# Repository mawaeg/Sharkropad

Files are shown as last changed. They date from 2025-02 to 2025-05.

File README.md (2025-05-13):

# Sharkropad

**Sharkropad** is an open-source hotswappable macropad supporting QMK/VIA.

This repository includes a custom pcb design, a 3d printed case and QMK/VIA firmware.

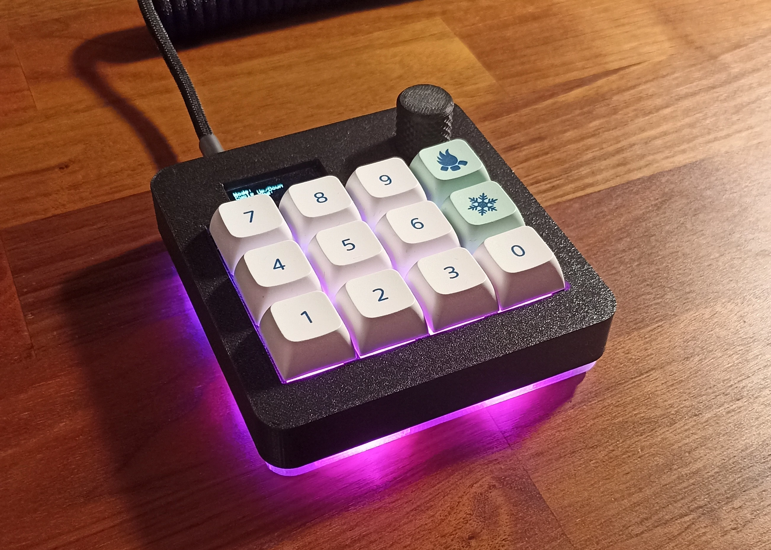
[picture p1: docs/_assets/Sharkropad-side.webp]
Sharkropad Logo


## Features
- **USB-C with ESD Protection**
- **Rotary Encoder**
- **OLED Display**
- **Customizable RGB Lighting**
- **Customizable keymap using VIA**
- **Hot-Swappable Switches**
- **Powered by a STM32L432 MCU**

## Getting Started

### Pcb

The Sharkropad is based on a custom pcb. You can find the manufacturing files in the latest release.

I got my pcb manufactured and assembled from [JLCPCB](https://jlcpcb.com/).

In case you want to assemble the pcb yourself you can find all the needed parts in the bom in the latest release.

### Other needed parts

| Part | Quantity  | Link (recommendation) | Note |
|---|---|---|---|
| filament of your choice | 50g | [3djake.de](https://www.3djake.de/polymaker/polyterra-pla-charcoal-black) | For the top parts (I used a matte black PLA filament)
| transparent filament | 30g | [redline-filament.com](https://redline-filament.com/collections/pla-filament/products/premium-pla-transparent?variant=50149105041672) | Transparent bottom parts for the underglow
| M2.5 Heat Inserts | 4 | [cnckitchen.store](https://cnckitchen.store/products/gewindeeinsatz-threaded-insert-m2-5-standard-100-stk-pcs) |
| M2.5 x 12 Screws | 4 | [cnckitchen.store](https://cnckitchen.store/products/m2-5-screw-stainless-steel-aisi-304-low-head?variant=47945362833743) |
| Protective buffer | 4 | [amazon.de](https://www.amazon.de/dp/B01N0X4Y38?ref=ppx_yo2ov_dt_b_fed_asin_title&th=1) |
| Keycaps | 12 | [aliexpress.com](https://de.aliexpress.com/item/1005006660909685.html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)
| Stranded wire | 10cm | tbd | Currently there is a problem with the pcb when using the underglow leds where a cable needs to be soldered
| Rotary Encoder | 1 | [42keebs.eu](https://42keebs.eu/shop/parts/ec11-rotary-encoder/?attribute_type=Bourns%20(larger%20body)) | This particular one works with the case and the knob
| OLED display | 1 | [42keebs.eu](https://42keebs.eu/shop/parts/oled-display-0-91-128x32/?attribute_pcb-colour=Black)
| OLED socket (low profile) | 1 | [42keebs.eu](https://42keebs.eu/shop/parts/low-profile-oled-sockets/) 
| Hotswap sockets | 12 | [42keebs.eu](https://42keebs.eu/shop/parts/kailh-mx-hot-swap-sockets/) | (2 x 10 sockets) !Cherry MX-style!
| Switches | 12 | [candykeys.com](https://candykeys.com/product/hmx-silent-sakura) | Any MX compatible switch is fine

### 3d printed case

The case consists of 4 3d printed parts:
- Bottom part of the case
- Top part of the case
- Plate for the switches
- Rotary encoder knob

The stl files for the 3d printed parts can be found under [cad/stl/](cad/stl/).

The parts are created with [OpenSCAD](https://openscad.org/) and the source code is stored at [cad/](cad/).

#### Print settings

For the bottom part of the case I used transparent PLA to make the underglow leds shine through.

For the top part of the case, the plate and the rotary encoder knob I used matte black PLA.

I printed the case and the plate with default print settings with a layer height of .2mm.

> **_NOTE:_** For the top and bottom case you will need some supports for the cutouts for the encoder and the screw heads. Default support settings should work just fine. (I like to use organic supports.)

The rotary encoder knob should be printed with a layer height of .2mm and at least 3 solid bottom layers.

### Building the Sharkropad

1. Get a PCB and prepare it by soldering the components onto it (if not already done through SMT assembly)
2. Assemble the rotary encoder, the oled socket and the hotswap sockets (if not already done)
3. Fix the issue with the pcb as shown in [this chapter](#fixing-the-pcb)

    <div style="display: flex;">
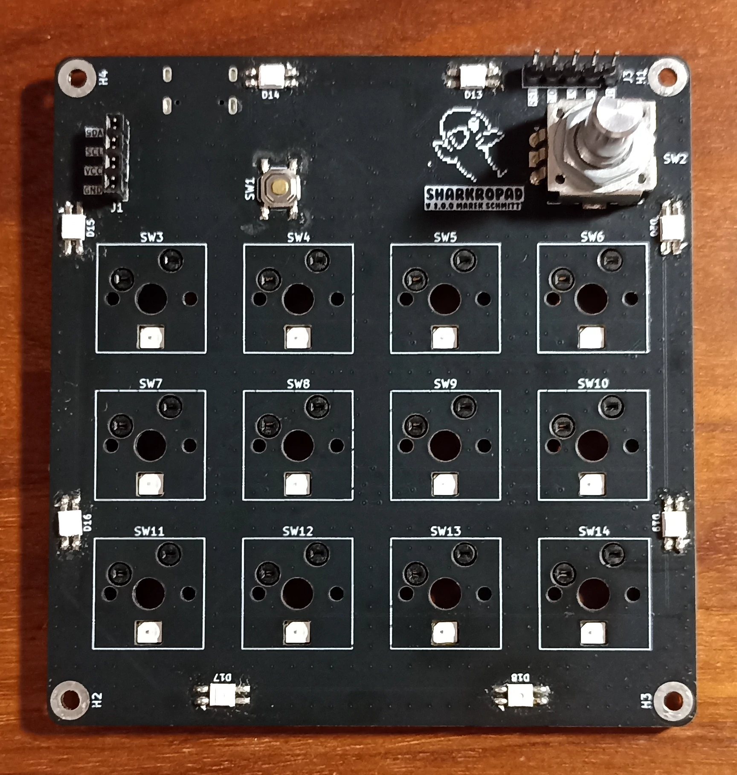
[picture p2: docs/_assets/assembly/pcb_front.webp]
        
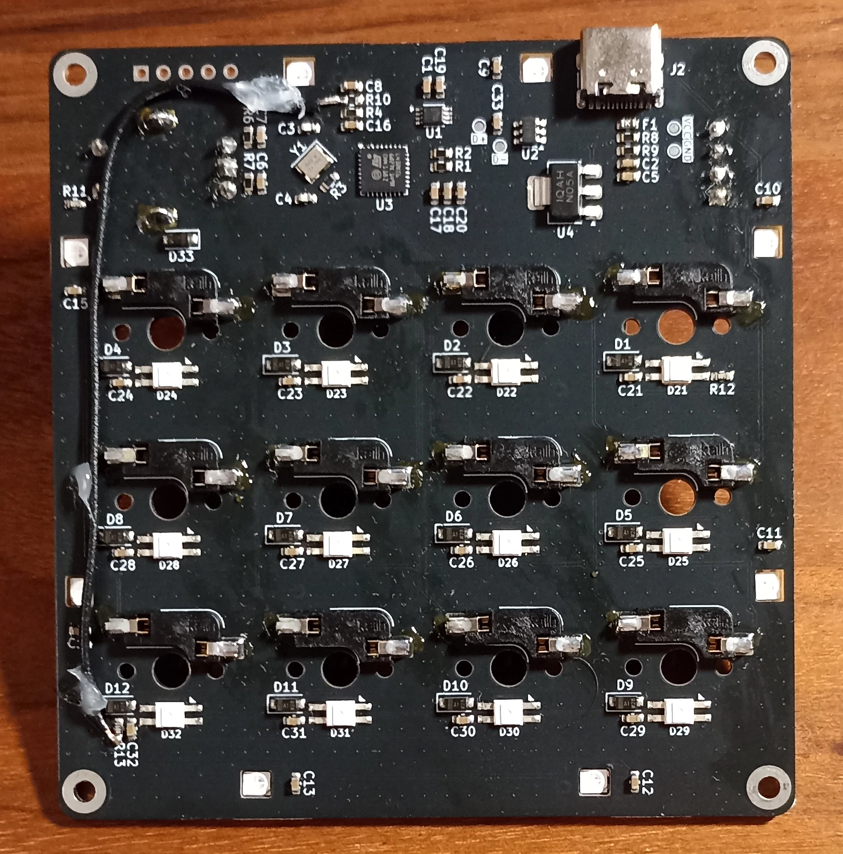
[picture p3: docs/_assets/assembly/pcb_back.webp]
        
    </div>

4. Place a foam (as shown) to support the OLED and mount the oled:

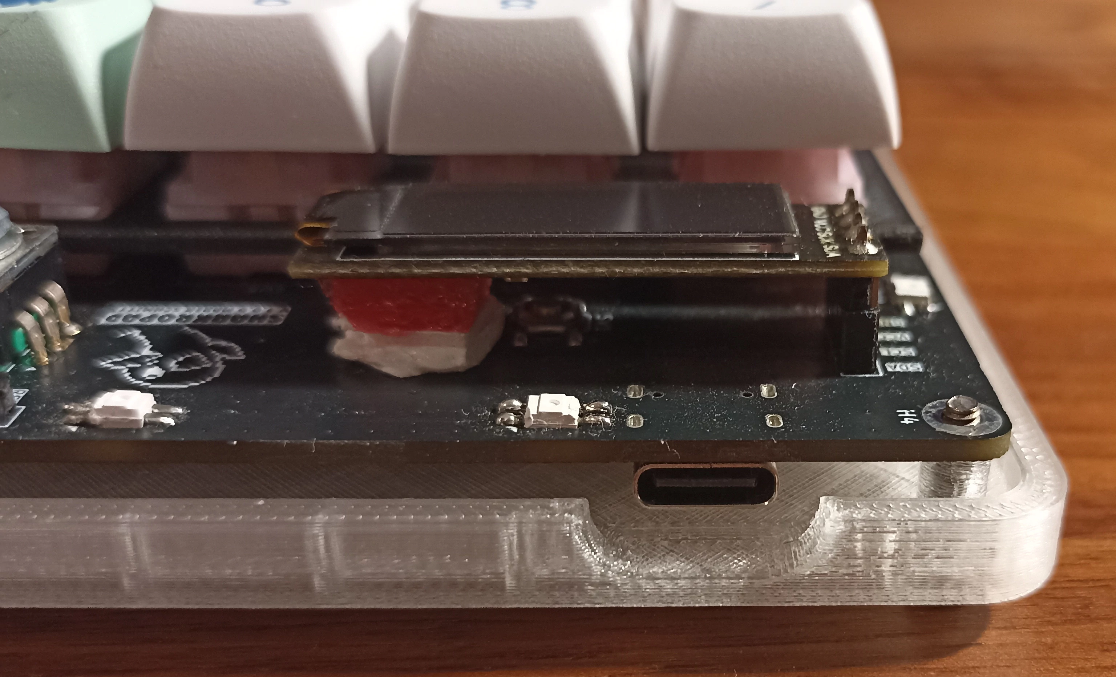
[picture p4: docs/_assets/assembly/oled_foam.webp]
     

5. Assemble the switches (put the plate between pcb and switches) and the keycaps
6. Insert the heat inserts into the holes provided in the top part:

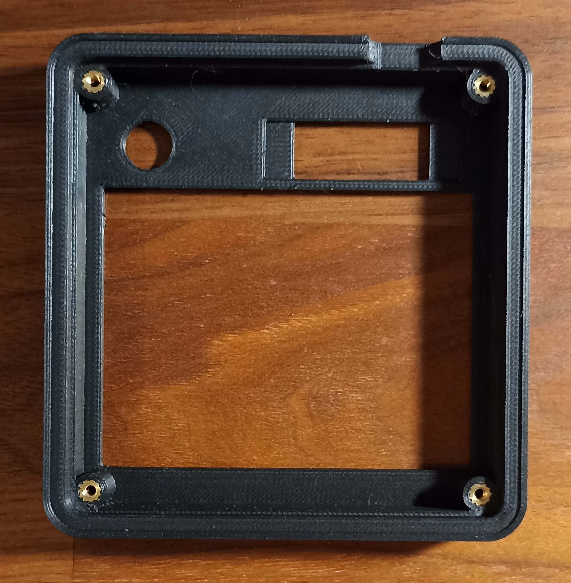
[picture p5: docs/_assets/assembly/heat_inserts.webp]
Heat inserts
    

7. Put the protective buffers on the bottom case to prevent the macropad from sliding around:

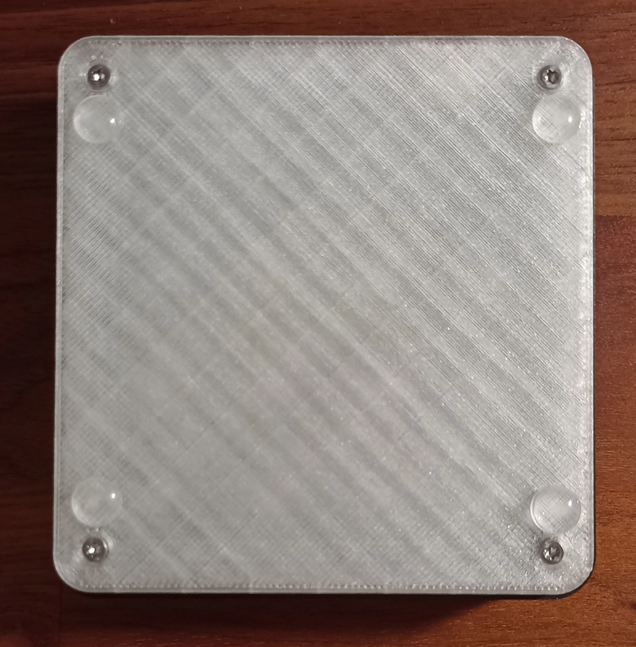
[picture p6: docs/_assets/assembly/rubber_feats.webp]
    

8. Screw the case together with the pcb in between and put the knob on the rotary encoder

### Flashing the firmware

> **_NOTE:_** Once the firmware is flashed once you can enter bootloader mode by disconnecting the macropad, pressing and holding the encoder knob while plugging it back in. Then the macropad is in bootloader mode and you can connect to it  and program it using the CubeProgrammer or flash using QMK.

1. Get the provided firmware in the latest release
    - If you want to be able to use VIA to modify the keymap you should use `sharkropad_via.bin`
    - If you only need QMK functionality you can also use ` sharkropad_default.bin`
    
2. Flash the firmware using the [STM32 CubeProgrammer](https://www.st.com/en/development-tools/stm32cubeprog.html) as shown below:

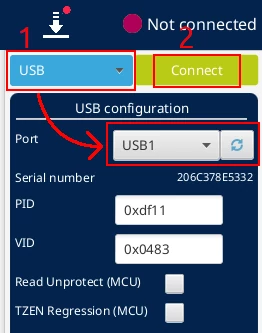
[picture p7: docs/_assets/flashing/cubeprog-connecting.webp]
Cube Programmer connecting

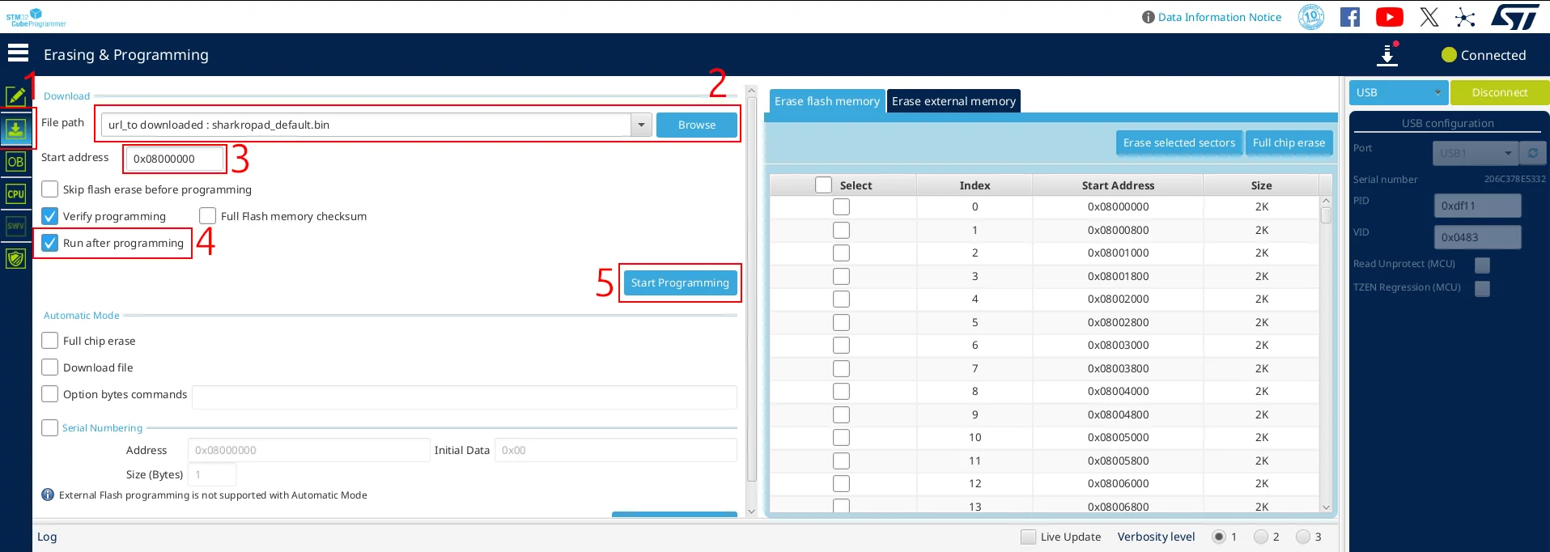
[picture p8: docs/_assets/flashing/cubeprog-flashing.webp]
Cube Programmer flashing


#### Flash using QMK

As the firmware is not currently in the qmk github repository flashing with QMK is more complicated.
- You need to setup your QMK Environment
- Copy the firmware into the QMK folder:
    - Copy the contents of the firmware folder to a folder named `sharkropad` under `qmk_firmware/keyboards`
    - Target structure: `qmk_firmware/keyboards/sharkropad`:

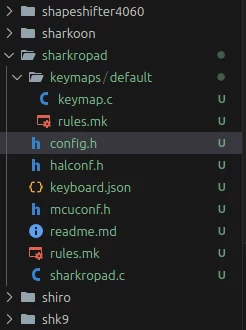
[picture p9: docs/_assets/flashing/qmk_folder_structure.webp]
QMK folder structure
      
- You can then compile and flash using qmk:
    ```shell
    qmk compile -kb sharkropad -km default
    qmk flash -kb sharkropad -km default
    ```

    or for via compatible firmware:
    ```shell
    qmk compile -kb sharkropad -km via
    qmk flash -kb sharkropad -km via
    ```

### Fixing the pcb

In the current design of the pcb, the rgb underglow and the rgb matrix for the keys are connected to different Output pins of the STM32.
However that is not supported by QMK. Therefore a cable needs to be manually soldered to also make the rgb underglow working:
- Remove the resistor R10
- Solder a cable from the left contact of R10 to the bottom contact of R13

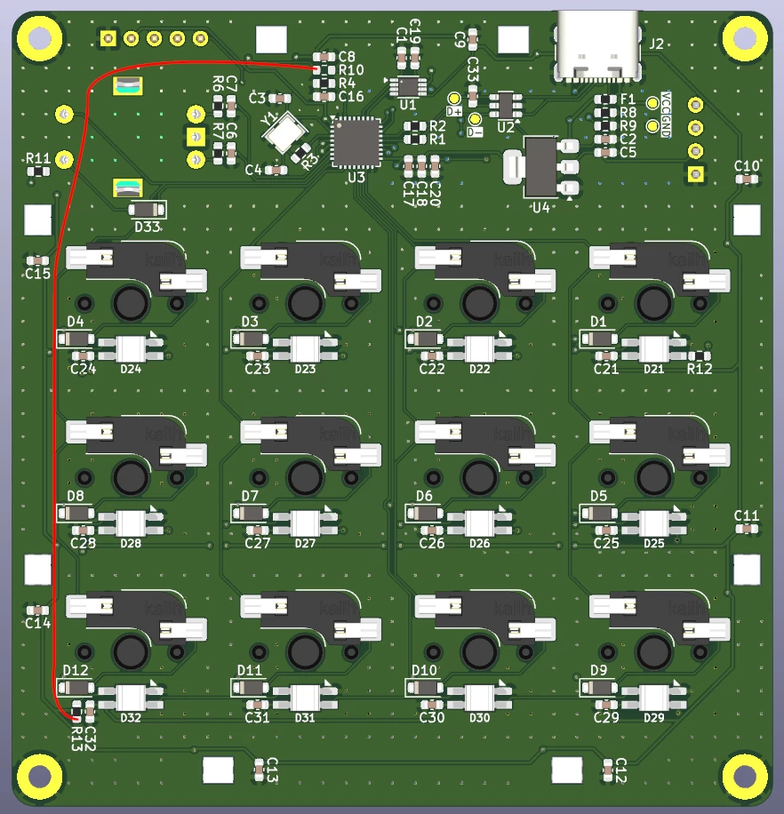
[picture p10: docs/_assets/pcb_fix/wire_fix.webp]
Pcb fix
    

## Customize the keymap using VIA

VIA is a tool that allows you to customize the keymap of your keyboard.

As the configuration for this macropad is not yet added to the via repository a manual step is needed to customize using VIA.

1. Open the VIA web app at [https://usevia.app/](https://usevia.app/)
2. Navigate to the settings and ensure the `Show Design tab` option is enabled

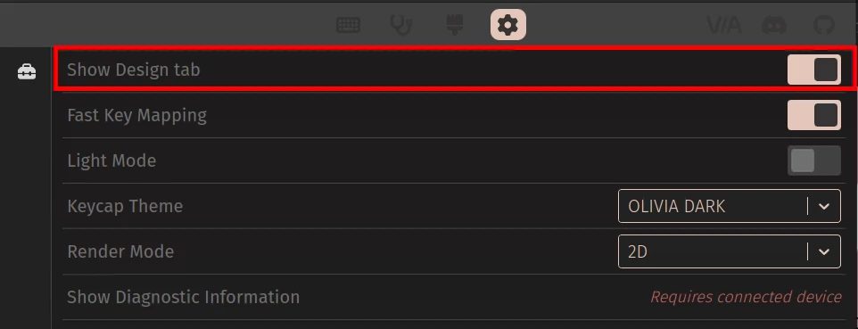
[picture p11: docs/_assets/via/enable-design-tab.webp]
Enable Design Tab
    

3. Open the design tab and press `Load` (Draft Definition)

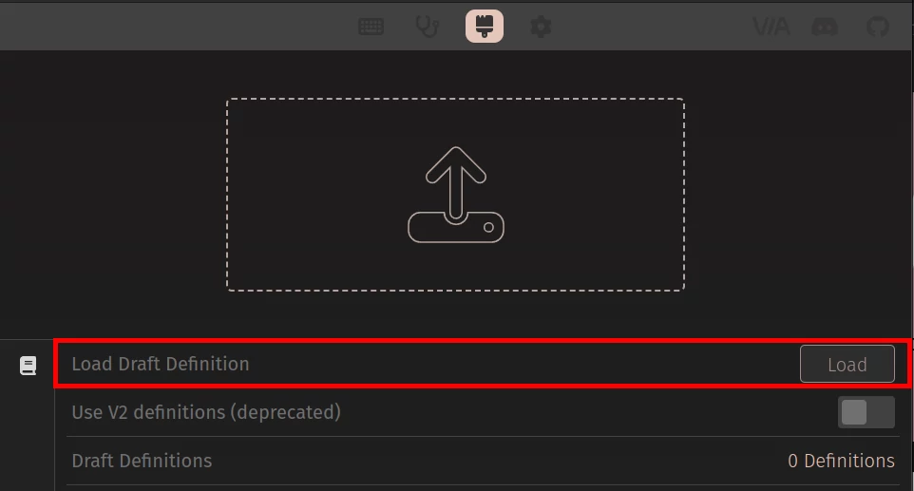
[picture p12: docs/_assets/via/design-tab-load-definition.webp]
Load definition
    

4. Select the `via.json` provided in this release. You should now see a model of the macropad:

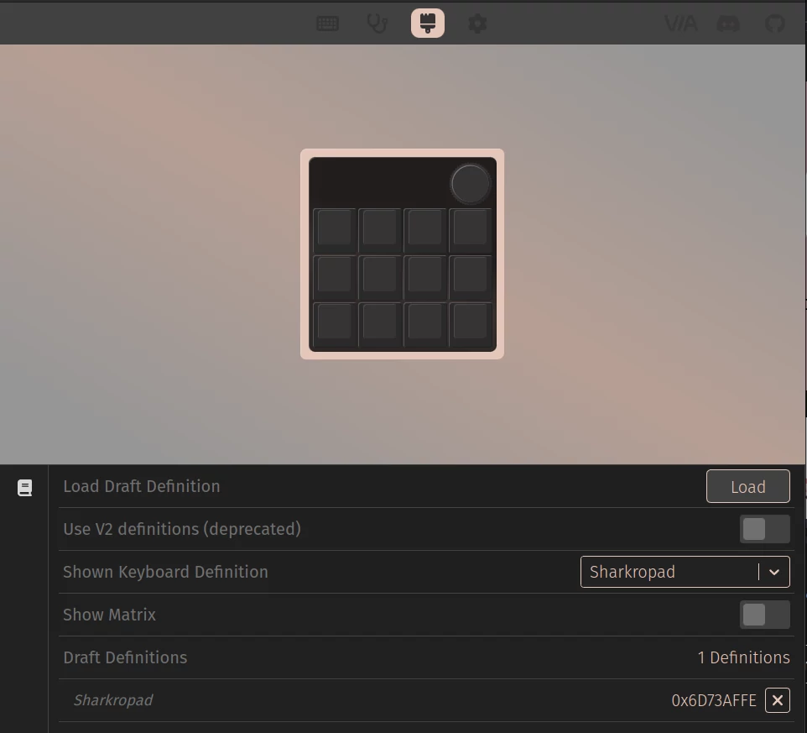
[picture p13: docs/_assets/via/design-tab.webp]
Design Tab Overview
    

5. You can now open the Customize window where you need to click `Authorize device +`

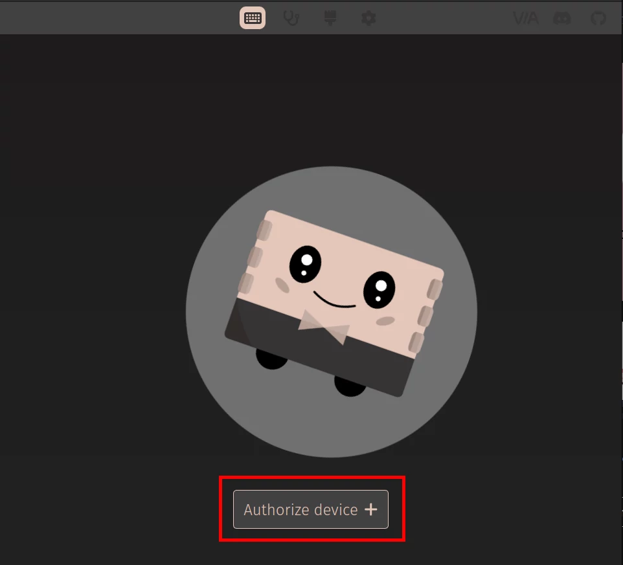
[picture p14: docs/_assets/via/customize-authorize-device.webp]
Authorize device
    

6. Select the device with Sharkropad in its name

You can now customize the individual keys and also customize the RGB Lighting:

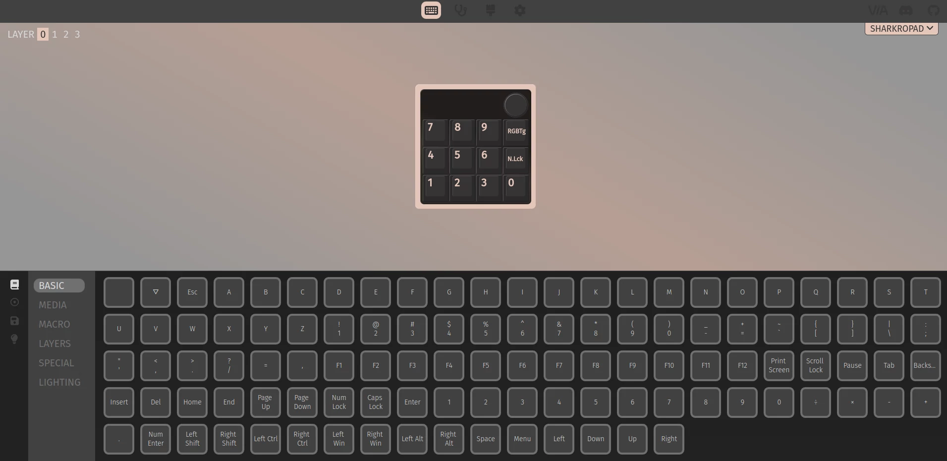
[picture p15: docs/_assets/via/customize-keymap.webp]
Customize keymap

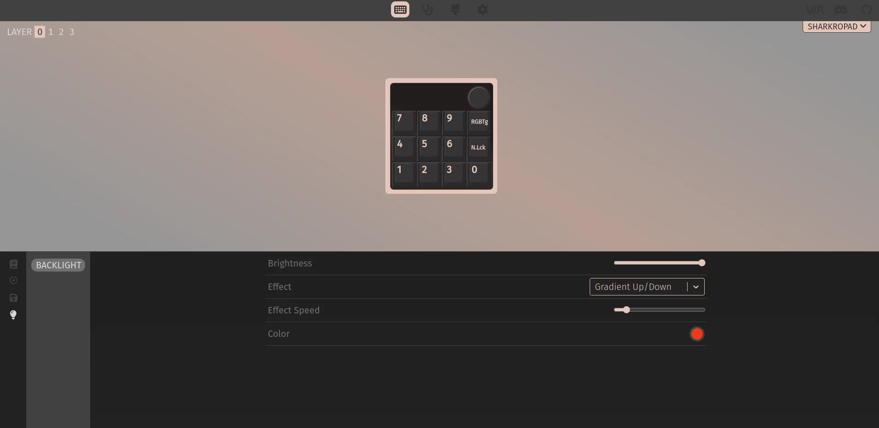
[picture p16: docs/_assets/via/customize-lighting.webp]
Customize lighting


## License

This project is licensed under the GNU General Public License v3.0. See the [LICENSE](LICENSE) file for details.

This project includes third-party components (libraries and fonts) that are licensed under their respective terms. These components are not covered by the GPLv3 license of this project. Users must adhere to the specific licenses provided in the respective directories.

### Libraries used for the pcb

For the creation of the pcb various libraries where used. 

A copy of most of them are included in this project to make the kicad project work without manually installing those libraries. 

Those libraries are stored under [/electronics/lib/](/electronics/lib/).

The libraries are licensed under their respective license. Please be aware of the `README.md` and `LICENSE.md` files in the lib folder.

### Font used on the pcb

The font used under the logo on the pcb is [Cherry Bomb One](https://github.com/satsuyako/CherryBomb).

A copy of the font is kept under [_assets/Cherry_Bomb_One](_assets/Cherry_Bomb_One). 
To make the font display correctly in KiCad you need to install it on your OS.

This font itself is licensed under the original OFL-1.1 License.
Please be aware of the License: [OFL.txt](_assets/Cherry_Bomb_One/OFL.txt)

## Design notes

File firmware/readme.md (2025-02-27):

# sharkropad

sharkropad

**Sharkropad** is an open-source hotswappable macropad.

* Keyboard Maintainer: [Marek Schmitt](https://github.com/mawaeg)
* Hardware Supported: PCB included in the [Sharkropad repository](https://github.com/mawaeg/sharkropad).
* Hardware Availability: PCB has to be sourced yourserlf

Make example for this keyboard (after setting up your build environment):

    make mawaeg/sharkropad:default

Flashing example for this keyboard:

    make mawaeg/sharkropad:default: flash

See the [build environment setup](https://docs.qmk.fm/#/getting_started_build_tools) and the [make instructions](https://docs.qmk.fm/#/getting_started_make_guide) for more information. Brand new to QMK? Start with our [Complete Newbs Guide](https://docs.qmk.fm/#/newbs).

## Bootloader

Enter the bootloader:
* **Bootmagic reset**: Hold down the rotary encoder knob and plug in the keyboard

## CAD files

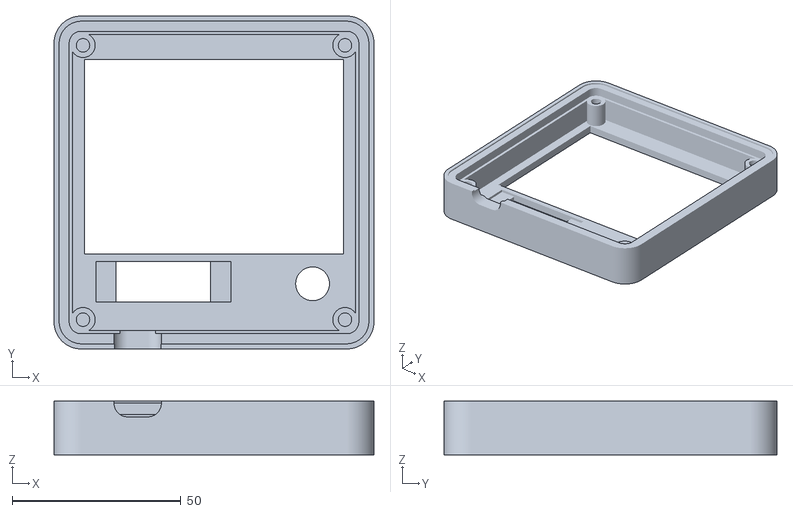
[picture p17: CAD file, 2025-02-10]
cad/stl/case_top.stl
94.8 x 98.6 x 16.0

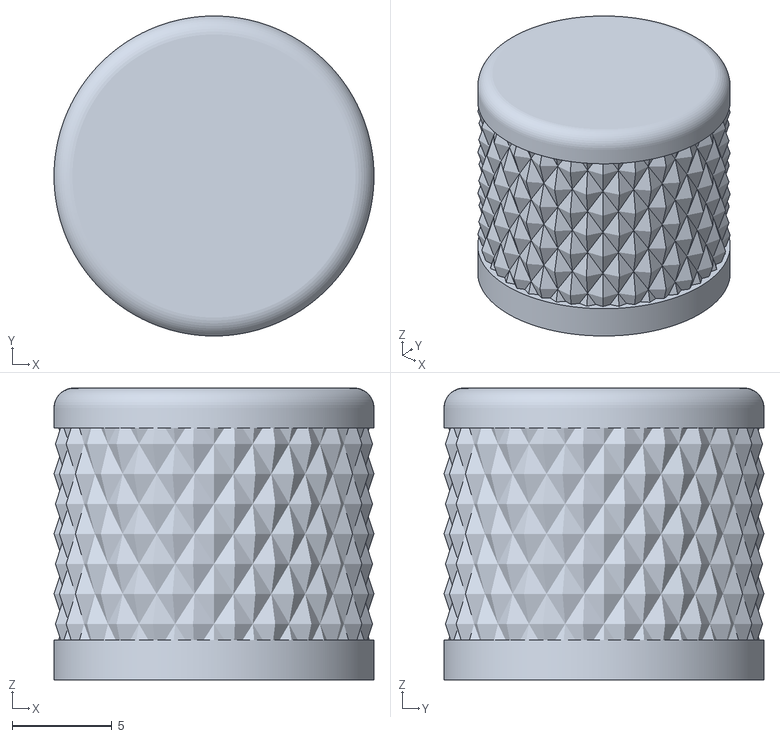
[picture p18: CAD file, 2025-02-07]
cad/stl/knob.stl
16.0 x 16.0 x 14.6

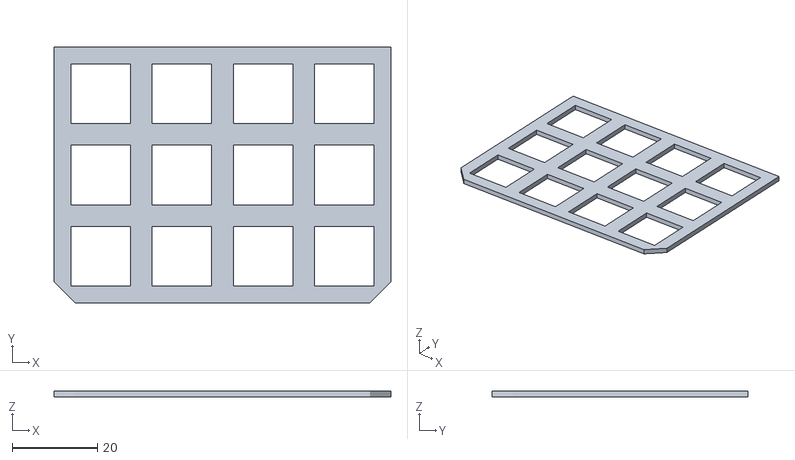
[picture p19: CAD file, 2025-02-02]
cad/stl/plate.stl
79.2 x 60.1 x 1.49

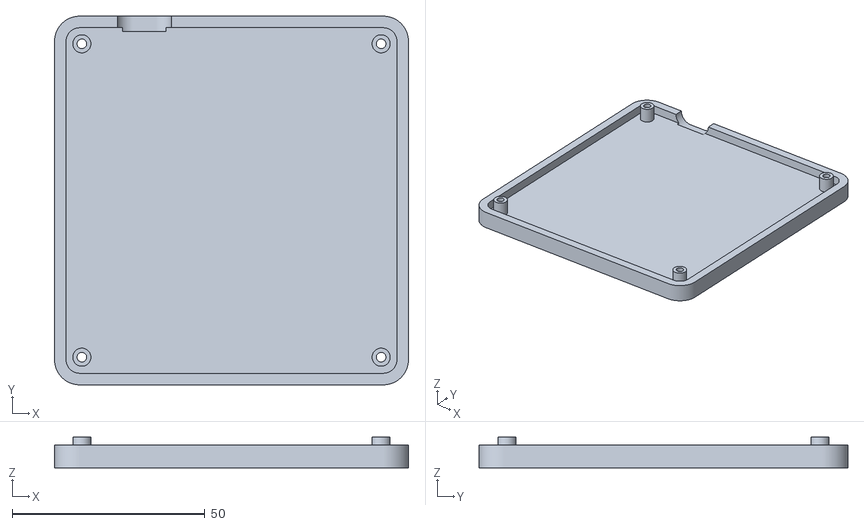
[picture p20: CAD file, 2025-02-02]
cad/stl/case_bottom.stl
91.8 x 95.6 x 8.00

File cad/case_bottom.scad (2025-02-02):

include <_utils/rounded_cube.scad>
include <_utils/create_cylinder.scad>
include <_utils/usb_c_cutout.scad>

$fa = 1;
$fs = 0.15;

//Base
base_x = 91.82;
base_y = 95.63;
base_z = 6;
wall_thickness = 3;
outer_radius = 6.540;
inner_radius = outer_radius-wall_thickness;
cylinder_h = 1;

//Screwholes
outer_screw_hole = 2.35;
inner_screw_hole = 1.25;

//USB-C cutout
usbc_depth= 4;
magic_port_location = 20.3;
usbc_port_z_translation = 3;


module base(){
union(){
    create_cylinder(5.001, outer_screw_hole, 2.5-0.001);
    difference(){
        rounded_cube(base_x, base_y, base_z, outer_radius, cylinder_h);

        translate([0,0,1.5+0.001])
        rounded_cube(base_x-(wall_thickness*2), base_y-(wall_thickness*2), base_z/2+0.001, inner_radius, cylinder_h);
    }
}
}

difference(){ 
    base();
    // Hole for the screw
    create_cylinder(10, inner_screw_hole, 1);   
    // Hole for the screwhead
    create_cylinder(2.001, 2.35, -2.001);
    usb_c_cutout(magic_port_location, base_y/2, usbc_port_z_translation, usbc_depth);
}

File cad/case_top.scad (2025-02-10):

include <_utils/rounded_cube.scad>
include <_utils/create_cylinder.scad>
include <_utils/usb_c_cutout.scad>

$fa = 1;
$fs = 0.15;

//Base
base_x = 94.82;
base_y = 98.63;
base_z = 16;
wall_thickness = 5.5;
outer_radius = 8.040;
inner_radius = outer_radius - wall_thickness;
cylinder_h = 1;

//Keycap_hole
keycap_x = 76.82;
keycap_y = 57.67;
keycap_y_border_dist = 12.86;

//Oled_hole (cutout to not show the edges of the oled and hole for the display)
oled_cutout_x = 40;
oled_hole_x = 28;
oled_y = 12;
oled_cutout_x_border_dist = 12.4;
oled_y_border_dist = 13.9;
oled_hole_x_border_dist = 18.4;

//Encoder_holes (cutout to make encoder clickable and hole for the shaft of the encoder)
encoder_cutout_r = 8.1;
encoder_cutout_x_border_dist = 10.1;
encoder_cutout_y_border_dist = 11.2;
encoder_hole_r = 5;
encoder_hole_x_border_dist = 13.2;
encoder_hole_y_border_dist = 14.3;

//Wall modifier
wall_mod_1_sub = 3.046;
wall_mod_2_sub = 9;

//USB-C cutout
usbc_depth= 7;
magic_port_location = 21.811;
usbc_translate_z = 7.3;



//Heat Insert holes
difference(){
create_cylinder(9, 3.6, -0.5);
create_cylinder(9, 2.001, -0.5+0.001);
}

difference(){
//Base
rounded_cube(base_x, base_y, base_z, outer_radius, cylinder_h);
translate([0,0,3+0.001])
rounded_cube(base_x-(wall_thickness*2), base_y-(wall_thickness*2), base_z, inner_radius, cylinder_h);
    
//Keycap_hole
translate([0,base_y/2-keycap_y/2-keycap_y_border_dist, -base_z/2+1.5])
cube([keycap_x, keycap_y, 3.004], center=true);

//Oled_hole
translate([-(base_x/2-oled_cutout_x/2-oled_cutout_x_border_dist),-(base_y/2-oled_y/2-oled_y_border_dist),-base_z/2+3.5])
cube([oled_cutout_x, oled_y, 3.004], center=true);
translate([-(base_x/2-oled_hole_x/2-oled_hole_x_border_dist),-(base_y/2-oled_y/2-oled_y_border_dist),-base_z/2+1.5])
cube([oled_hole_x, oled_y, 3.004], center=true);

//Encoder_hole
translate([base_x/2-encoder_cutout_r-encoder_cutout_x_border_dist,-(base_y/2-encoder_cutout_r-encoder_cutout_y_border_dist),-base_z/2+1.5-2])
cylinder(h=3.004, r=encoder_cutout_r, center=true);
translate([base_x/2-encoder_hole_r-encoder_hole_x_border_dist,-(base_y/2-encoder_hole_r-encoder_hole_y_border_dist),-base_z/2+1.5])
cylinder(h=3.004, r=encoder_hole_r, center=true);

//Wall modifier 1
translate([0,0,base_z/2+15.4/2-0.3]) //For some reason we ned -0.3 here?
rounded_cube(base_x-wall_mod_1_sub, base_y-wall_mod_1_sub, base_z, 6.64, cylinder_h);
//Wall modifier 2
translate([0,0,base_z/2+12/2-2])
rounded_cube(base_x-wall_mod_2_sub, base_y-wall_mod_2_sub, base_z, 3.54, cylinder_h);

//USB-C cutout
usb_c_cutout(magic_port_location, -(base_y/2)+6, usbc_translate_z, usbc_depth);
}

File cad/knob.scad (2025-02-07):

include <_utils/knurled_cylinder.scad>

$fa = 1;
$fs = 0.15;

layer_height = 0.2;
bottom_solid_layers = 3;
bottom_solid = layer_height*bottom_solid_layers;

knob_radius = 8;
knob_height = 14.6;
knob_border = 2;

knob_bevel = 0;
knob_knurl_width = 2;
knob_knurl_height = 3;
knob_knurl_depth = 0.5;

knob_top_clearance = 1.6; // Depth of the hole on the open side

shaft_height = knob_height-knob_top_clearance-bottom_solid;
d_tolerance = 0.15; // The tolerance for the D hole for the encoder
d_cut = 1.5; // Amount that should be cut for the D hole for the encoder


difference(){
    //Body
    translate([0,0, knob_border/2])
        union(){
            cylinder(r=knob_radius, h=knob_border, center=true);

            translate([0, 0, knob_border/2])
                knurled_cylinder(height=knob_height-(2*knob_border), diameter=knob_radius*2-knob_knurl_depth, bevel=knob_bevel, knurl_depth=knob_knurl_depth, knurl_width=knob_knurl_width, knurl_height=knob_knurl_height);

            //Rounded top edge
            hull() {
                translate([0, 0, knob_height-1.5*knob_border]) cylinder(r=knob_radius, h=knob_border/2);
                translate([0,0,knob_height-knob_border])rotate_extrude() translate([knob_radius-1, 0]) circle(r=1);
            }
        }
    //Hole in the knob
    translate([0,0, -knob_height-0.001 + knob_top_clearance])
        cylinder(r=knob_radius-2, h=knob_height+0.001);

    //D cutout for encoder
    translate([0,0, knob_height-(shaft_height/2)-bottom_solid-0.001])
    difference(){
        cylinder(r=3 + d_tolerance/2, h=shaft_height+0.001, center=true);
        translate([-(d_cut+4.5/2 + d_tolerance), 0, 0]) 
            cube([4.5, 10, shaft_height+0.002], center=true);
    }
}

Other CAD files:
cad/plate.scad
cad/_utils/create_cylinder.scad
cad/_utils/knurled_cylinder.scad
cad/_utils/rounded_cube.scad
cad/_utils/usb_c_cutout.scad

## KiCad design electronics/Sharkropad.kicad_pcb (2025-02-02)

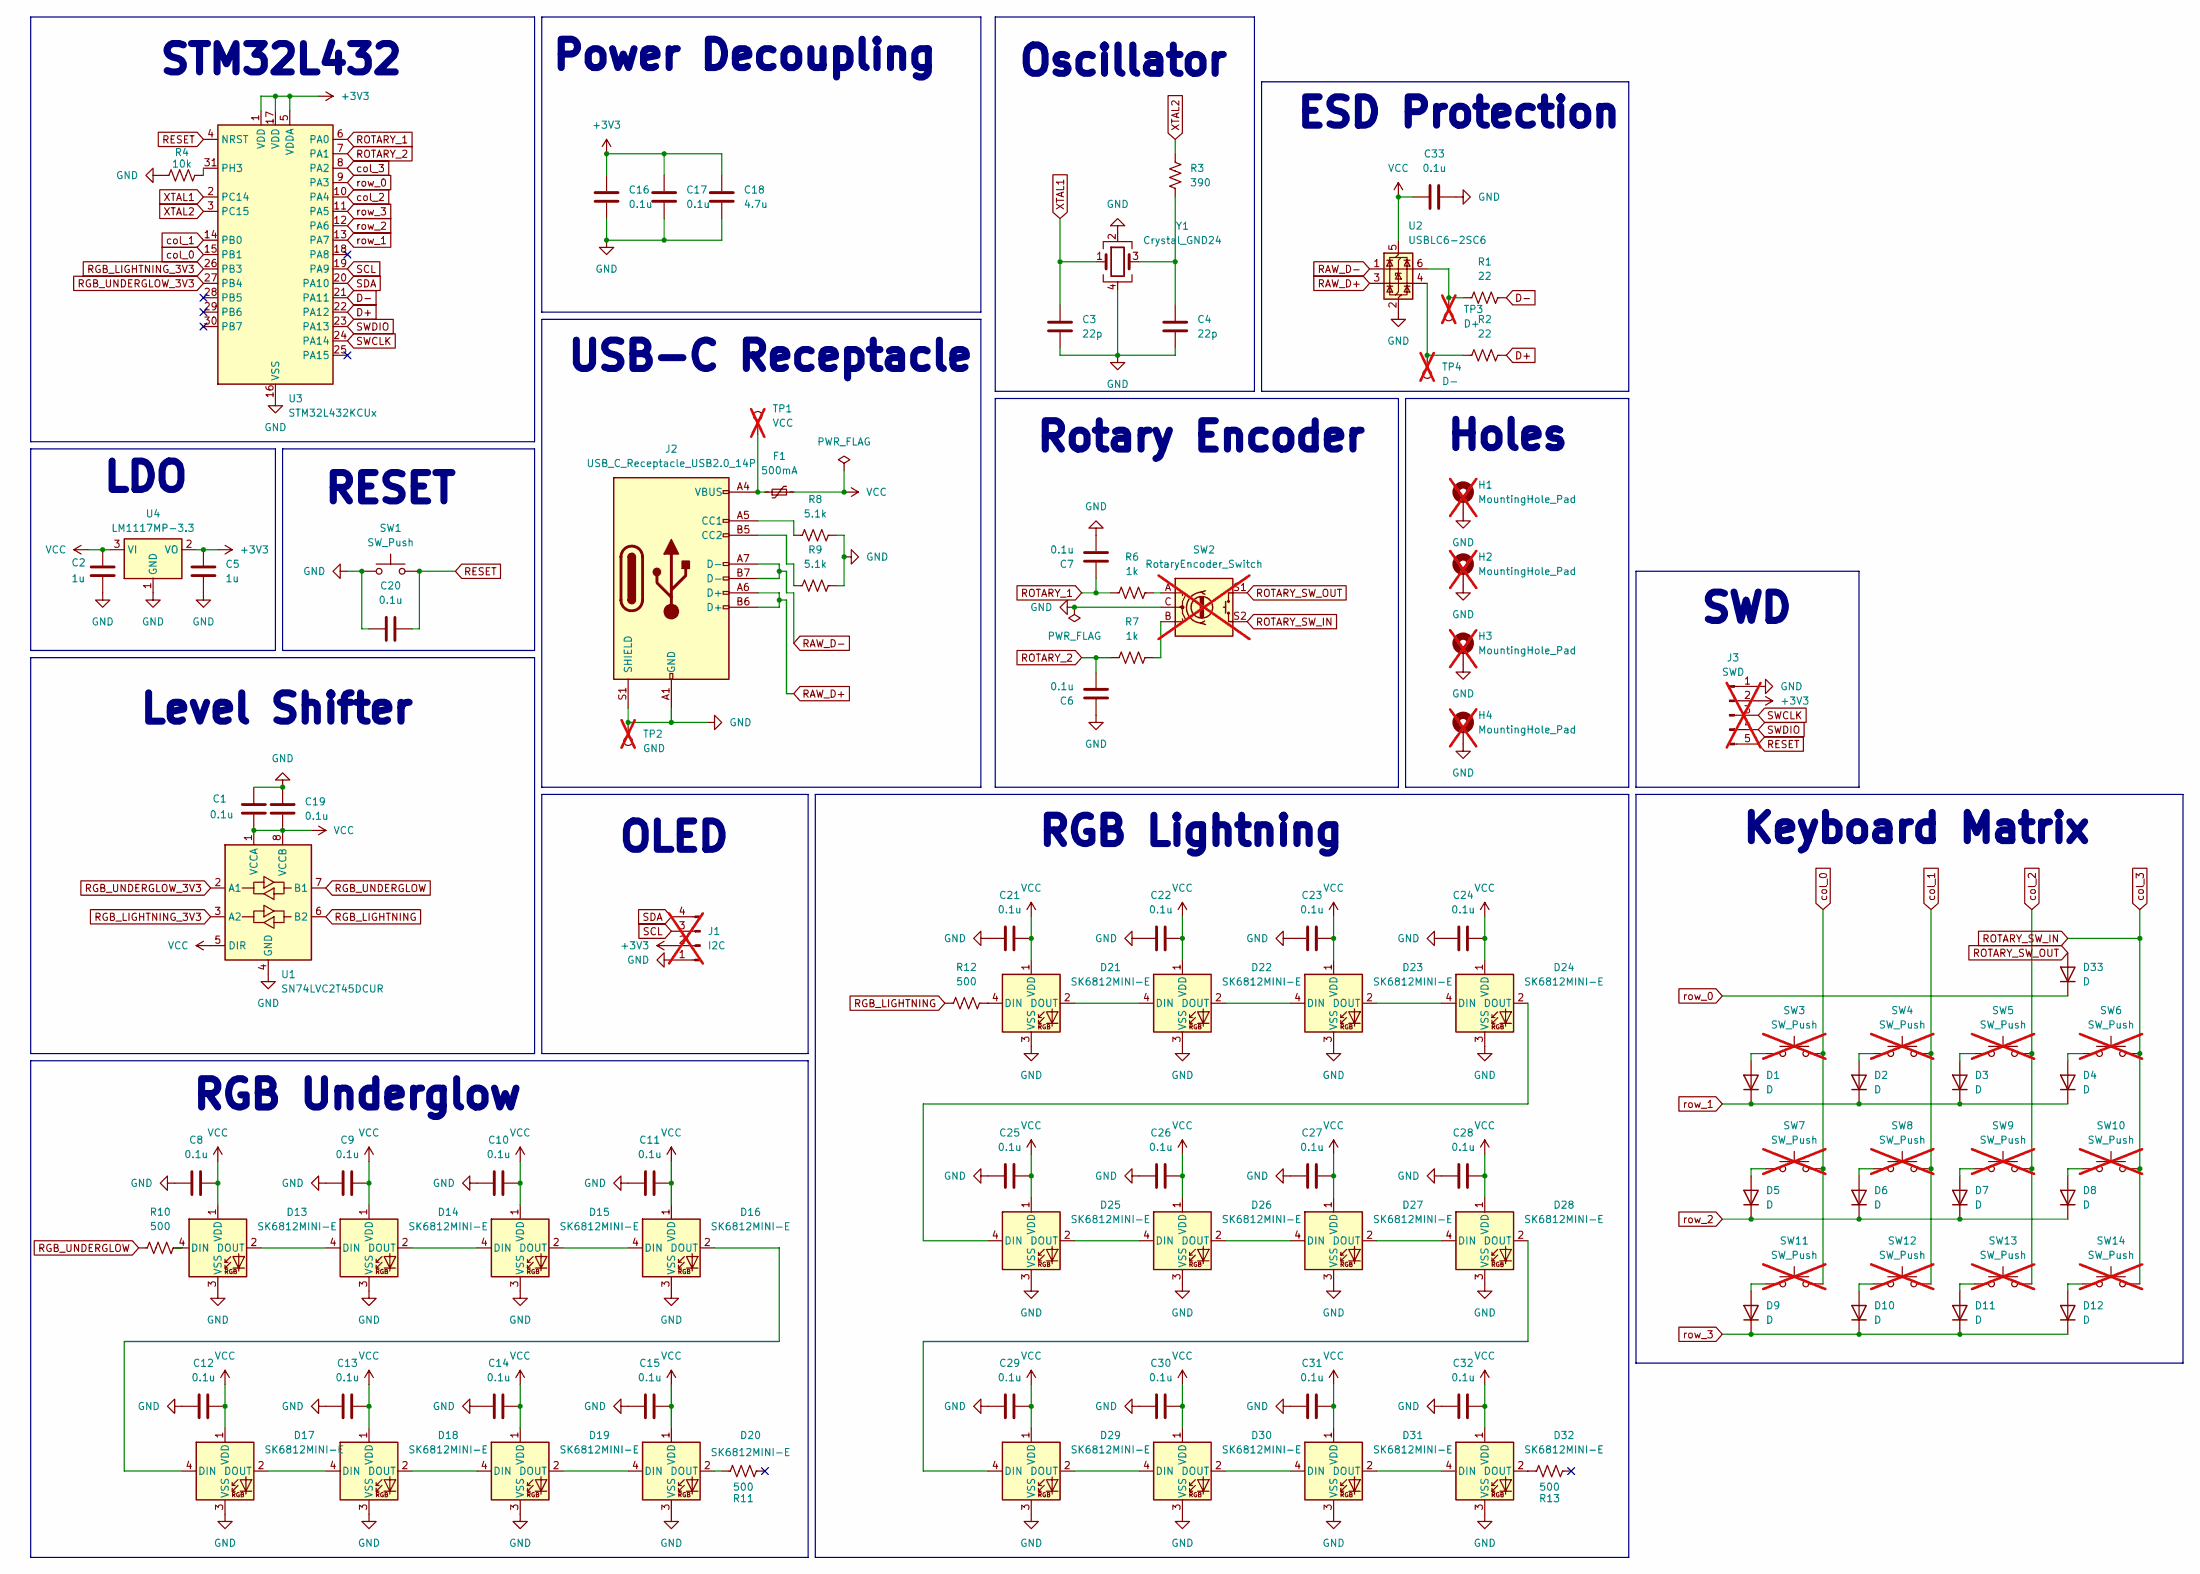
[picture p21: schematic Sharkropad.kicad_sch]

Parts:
C1, C6, C7, C8, C9, C10, C11, C12, C13, C14, C15, C16, C17, C19, C20, C21, C22, C23, C24, C25, C26, C27, C28, C29, C30, C31, C32, C33: 0.1u; C_0603_1608Metric; MPN GCM188R71C104KA37J
C2, C5: 1u; C_0603_1608Metric; MPN GRM188C81E105KAADD
C3, C4: 22p; C_0603_1608Metric; MPN GRM1885C2A220JA01J
C18: 4.7u; C_0603_1608Metric; MPN GCJ188C70J475KE02D
D1, D2, D3, D4, D5, D6, D7, D8, D9, D10, D11, D12, D33: D; D_SOD-123F; MPN BAS16H,115
D13, D14, D15, D16, D17, D18, D19, D20, D21, D22, D23, D24, D25, D26, D27, D28, D29, D30, D31, D32: SK6812MINI-E; SK6812-MINI-E; MPN SK6812MINI-E
F1: 500mA; Fuse_0603_1608Metric; MPN MF-FSML050/8-2
H1, H2, H3, H4: MountingHole_Pad; MountingHole_2.5mm_Pad; not fitted
J1: I2C; PinHeader_1x04_P2.54mm_Vertical; not fitted
J2: USB_C_Receptacle_USB2.0_14P; USB_C_Receptacle_GCT_USB4105-xx-A_16P_TopMnt_Horizontal; MPN USB4105-GF-A-120
J3: SWD; PinHeader_1x05_P2.54mm_Vertical; not fitted
R1, R2: 22; R_0603_1608Metric; MPN CRCW060322R0FKEA
R3: 390; R_0603_1608Metric; MPN CRCW0603390RFKEA
R4: 10k; R_0603_1608Metric; MPN CRCW060310K0FKEI
R6, R7: 1k; R_0603_1608Metric; MPN CRCW06031K00FKED
R8, R9: 5.1k; R_0603_1608Metric; MPN CRCW06035K10FKEC
R10, R11, R12, R13: 500; R_0603_1608Metric; MPN CRCW0603499RFKEA
SW1: SW_Push; SW_SPST_TL3342; MPN TL3342F160QG
SW2: RotaryEncoder_Switch; RotaryEncoder_Alps_EC11E-Switch_Vertical_H20mm; not fitted
SW3, SW4, SW5, SW6, SW7, SW8, SW9, SW10, SW11, SW12, SW13, SW14: SW_Push; SW_Hotswap_Kailh_MX_1.00u; not fitted
TP1: VCC; TestPoint_Pad_D1.0mm; not fitted
TP2: GND; TestPoint_Pad_D1.0mm; not fitted
TP3: D+; TestPoint_Pad_D1.0mm; not fitted
TP4: D-; TestPoint_Pad_D1.0mm; not fitted
U1: SN74LVC2T45DCUR; VSSOP-8_2.3x2mm_P0.5mm; MPN SN74LVC2T45DCURE4
U2: USBLC6-2SC6; SOT-23-6; MPN USBLC6-2SC6
U3: STM32L432KCUx; QFN-32-1EP_5x5mm_P0.5mm_EP3.45x3.45mm; MPN STM32L432KCU6
U4: LM1117MP-3.3; SOT-223-3_TabPin2; MPN LM1117MPX-3.3/NOPB
Y1: Crystal_GND24; Crystal_SMD_SeikoEpson_FA238-4Pin_3.2x2.5mm; MPN ECS-80-18-33-JGN-TR

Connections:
+3V3: C5.1, C16.1, C17.1, C18.1, J1.2, J3.2, U3.1 (VDD), U3.5 (VDDA), U3.17 (VDD), U4.2 (VO)
D+: R2.1, U3.22 (PA12)
D-: R1.1, U3.21 (PA11)
GND: C1.1, C2.2, C3.2, C4.2, C5.2, C6.1, C7.2, C8.1, C9.1, C10.1, C11.1, C12.1, C13.1, C14.1, C15.1, C16.2, C17.2, C18.2, C19.1, C20.2, C21.1, C22.1, C23.1, C24.1, C25.1, C26.1, C27.1, C28.1, C29.1, C30.1, C31.1, C32.1, C33.2, D13.3 (VSS), D14.3 (VSS), D15.3 (VSS), D16.3 (VSS), D17.3 (VSS), D18.3 (VSS), D19.3 (VSS), D20.3 (VSS), D21.3 (VSS), D22.3 (VSS), D23.3 (VSS), D24.3 (VSS), D25.3 (VSS), D26.3 (VSS), D27.3 (VSS), D28.3 (VSS), D29.3 (VSS), D30.3 (VSS), D31.3 (VSS), D32.3 (VSS), H1.1, H2.1, H3.1, H4.1, J1.1, J2.A1 (GND), J2.A12 (GND), J2.B1 (GND), J2.B12 (GND), J2.S1 (SHIELD), J3.1, R4.2, R8.2, R9.2, SW1.1, SW2.C, TP2.1, U1.4 (GND), U2.2 (GND), U3.16 (VSS), U3.32 (VSS), U3.33 (VSS), U4.1 (GND), Y1.2, Y1.4
unnamed: C4.1, R3.2, Y1.3
unnamed: D1.2 (A), SW3.1
unnamed: D2.2 (A), SW4.1
unnamed: D3.2 (A), SW5.1
unnamed: D4.2 (A), SW6.1
unnamed: D5.2 (A), SW7.1
unnamed: D6.2 (A), SW8.1
unnamed: D7.2 (A), SW9.1
unnamed: D8.2 (A), SW10.1
unnamed: D9.2 (A), SW11.1
unnamed: D10.2 (A), SW12.1
unnamed: D11.2 (A), SW13.1
unnamed: D12.2 (A), SW14.1
unnamed: D13.4 (DIN), R10.2
unnamed: D13.2 (DOUT), D14.4 (DIN)
unnamed: D14.2 (DOUT), D15.4 (DIN)
unnamed: D15.2 (DOUT), D16.4 (DIN)
unnamed: D16.2 (DOUT), D17.4 (DIN)
unnamed: D17.2 (DOUT), D18.4 (DIN)
unnamed: D18.2 (DOUT), D19.4 (DIN)
unnamed: D19.2 (DOUT), D20.4 (DIN)
unnamed: D20.2 (DOUT), R11.1
unnamed: D21.4 (DIN), R12.2
unnamed: D21.2 (DOUT), D22.4 (DIN)
unnamed: D22.2 (DOUT), D23.4 (DIN)
unnamed: D23.2 (DOUT), D24.4 (DIN)
unnamed: D24.2 (DOUT), D25.4 (DIN)
unnamed: D25.2 (DOUT), D26.4 (DIN)
unnamed: D26.2 (DOUT), D27.4 (DIN)
unnamed: D27.2 (DOUT), D28.4 (DIN)
unnamed: D28.2 (DOUT), D29.4 (DIN)
unnamed: D29.2 (DOUT), D30.4 (DIN)
unnamed: D30.2 (DOUT), D31.4 (DIN)
unnamed: D31.2 (DOUT), D32.4 (DIN)
unnamed: D32.2 (DOUT), R13.1
unnamed: F1.1, J2.A4 (VBUS), J2.A9 (VBUS), J2.B4 (VBUS), J2.B9 (VBUS), TP1.1
unnamed: J2.A5 (CC1), R8.1
unnamed: J2.B5 (CC2), R9.1
unnamed: R1.2, TP3.1, U2.6 (I/O1)
unnamed: R2.2, TP4.1, U2.4 (I/O2)
unnamed: R6.2, SW2.A
unnamed: R7.2, SW2.B
unnamed: R4.1, U3.31 (PH3)
RAW_D+: J2.A6 (D+), J2.B6 (D+), U2.3 (I/O2)
RAW_D-: J2.A7 (D-), J2.B7 (D-), U2.1 (I/O1)
RESET: C20.1, J3.5, SW1.2, U3.4 (NRST)
RGB_LIGHTNING: R12.1, U1.6 (B2)
RGB_LIGHTNING_3V3: U1.3 (A2), U3.26 (PB3)
RGB_UNDERGLOW: R10.1, U1.7 (B1)
RGB_UNDERGLOW_3V3: U1.2 (A1), U3.27 (PB4)
ROTARY_1: C7.1, R6.1, U3.6 (PA0)
ROTARY_2: C6.2, R7.1, U3.7 (PA1)
ROTARY_SW_IN: SW2.S2, SW6.2, SW10.2, SW14.2, U3.8 (PA2)
ROTARY_SW_OUT: D33.2 (A), SW2.S1
SCL: J1.3, U3.19 (PA9)
SDA: J1.4, U3.20 (PA10)
SWCLK: J3.3, U3.24 (PA14)
SWDIO: J3.4, U3.23 (PA13)
VCC: C1.2, C2.1, C8.2, C9.2, C10.2, C11.2, C12.2, C13.2, C14.2, C15.2, C19.2, C21.2, C22.2, C23.2, C24.2, C25.2, C26.2, C27.2, C28.2, C29.2, C30.2, C31.2, C32.2, C33.1, D13.1 (VDD), D14.1 (VDD), D15.1 (VDD), D16.1 (VDD), D17.1 (VDD), D18.1 (VDD), D19.1 (VDD), D20.1 (VDD), D21.1 (VDD), D22.1 (VDD), D23.1 (VDD), D24.1 (VDD), D25.1 (VDD), D26.1 (VDD), D27.1 (VDD), D28.1 (VDD), D29.1 (VDD), D30.1 (VDD), D31.1 (VDD), D32.1 (VDD), F1.2, U1.1 (VCCA), U1.5 (DIR), U1.8 (VCCB), U2.5 (VBUS), U4.3 (VI)
XTAL1: C3.1, U3.2 (PC14), Y1.1
XTAL2: R3.1, U3.3 (PC15)
col_0: SW3.2, SW7.2, SW11.2, U3.15 (PB1)
col_1: SW4.2, SW8.2, SW12.2, U3.14 (PB0)
col_2: SW5.2, SW9.2, SW13.2, U3.10 (PA4)
row_0: D33.1 (K), U3.9 (PA3)
row_1: D1.1 (K), D2.1 (K), D3.1 (K), D4.1 (K), U3.13 (PA7)
row_2: D5.1 (K), D6.1 (K), D7.1 (K), D8.1 (K), U3.12 (PA6)
row_3: D9.1 (K), D10.1 (K), D11.1 (K), D12.1 (K), U3.11 (PA5)

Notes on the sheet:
STM32L432
LDO
USB-C Receptacle
ESD Protection
Holes
SWD
Level Shifter
Power Decoupling
Oscillator
RGB Underglow
Keyboard Matrix
RESET
RGB Lightning
OLED
Rotary Encoder

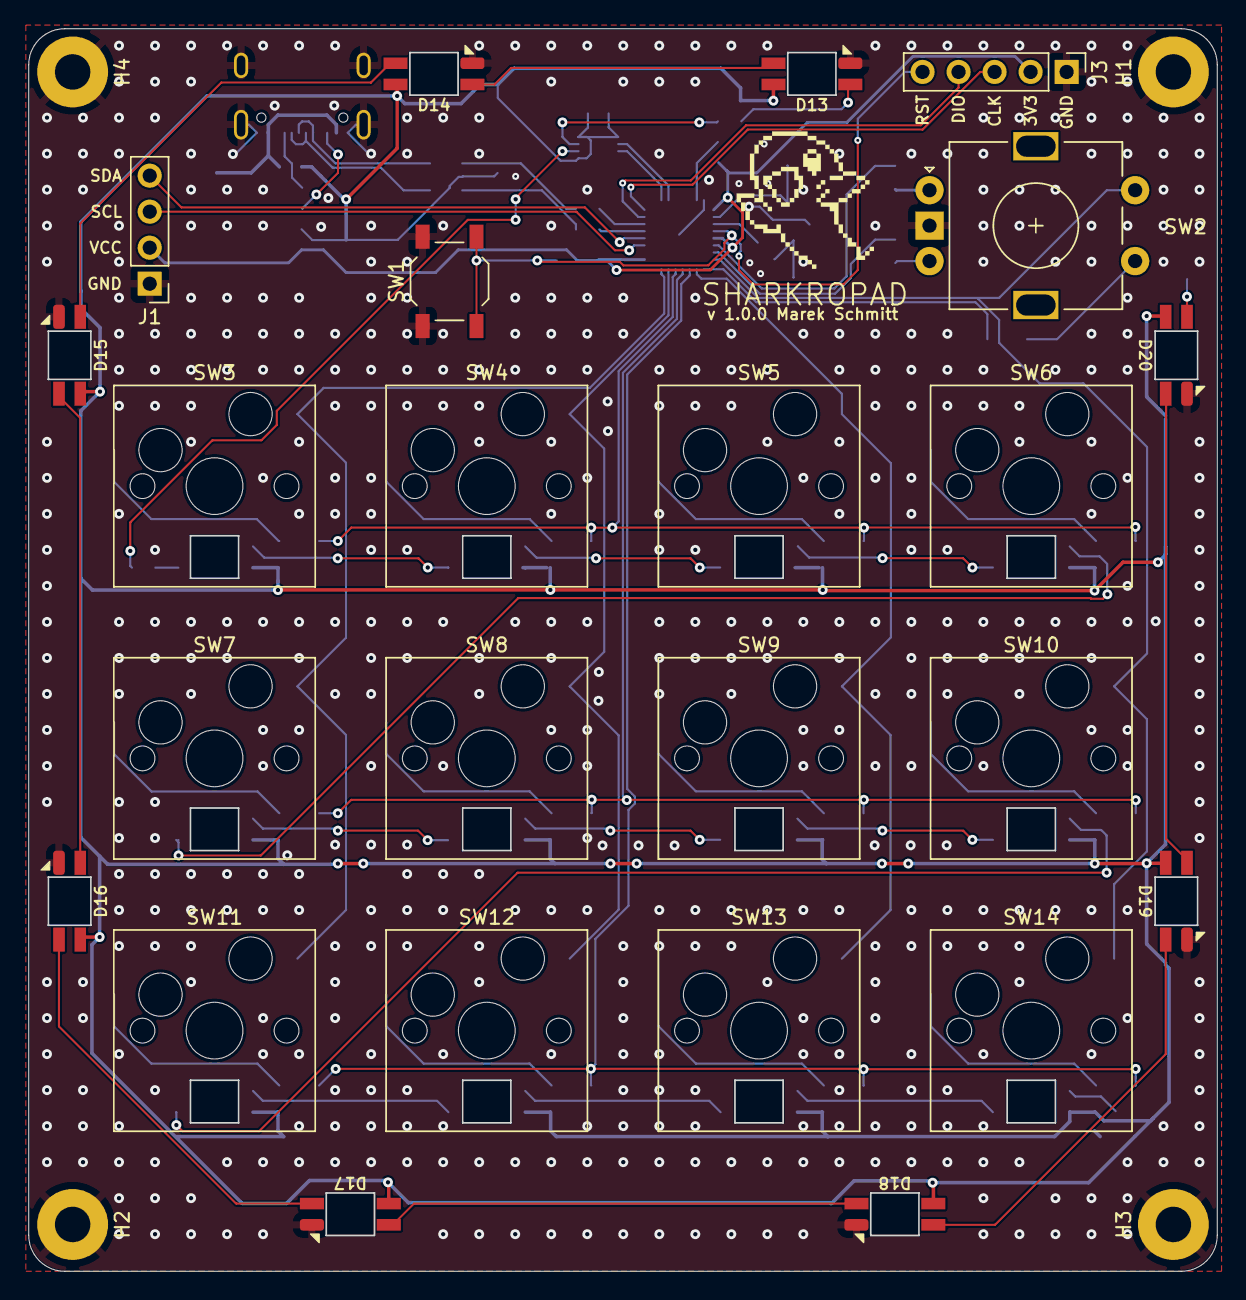
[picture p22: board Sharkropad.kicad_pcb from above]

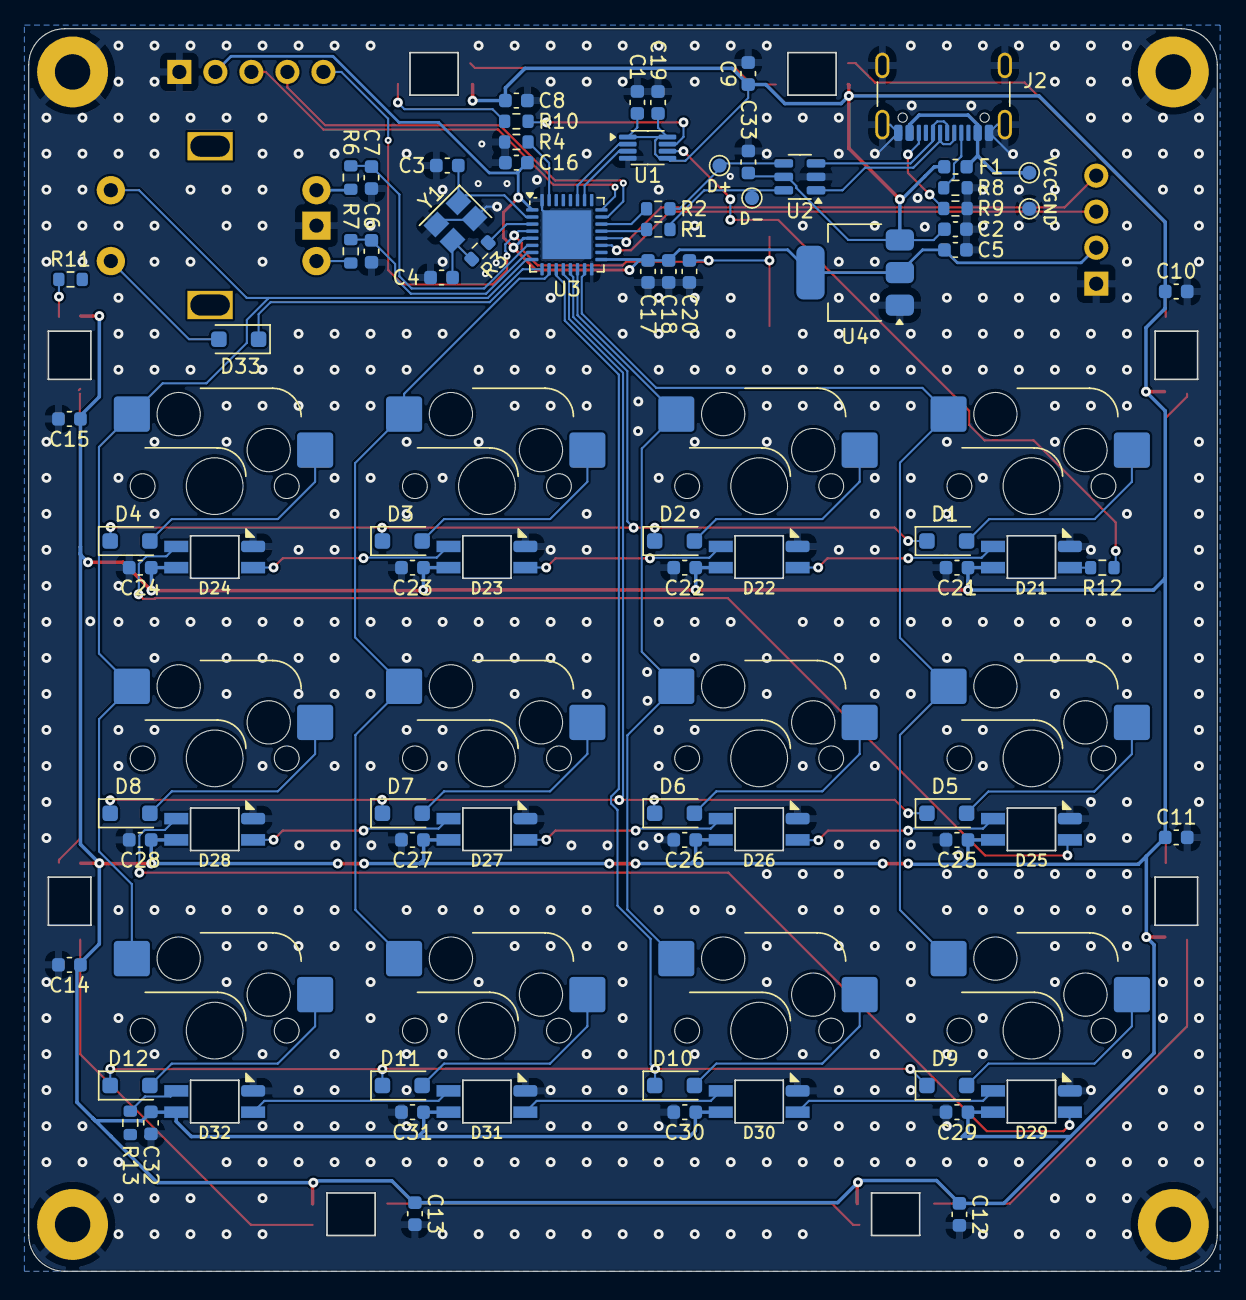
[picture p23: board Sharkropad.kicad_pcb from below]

Board: 2 copper layers, 83.8 x 87.6 mm, 109 parts (81 on the bottom side), 72 nets.

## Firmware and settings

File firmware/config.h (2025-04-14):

#define STM32_FLASH_SECTORS_PER_BANK 128

#define I2C1_SCL_PIN A9
#define I2C1_SDA_PIN A10

#define WS2812_PWM_DRIVER PWMD2
#define WS2812_PWM_CHANNEL 2
#define WS2812_PWM_PAL_MODE 1
#define WS2812_PWM_DMA_STREAM STM32_DMA1_STREAM2
#define WS2812_PWM_DMA_CHANNEL 4

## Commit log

2025-02-07 Add scad based knob
    [knob.scad, knob.stl, knurled_cylinder.scad]
2025-02-10 Add missing cutouts for encoder and oled
    [case_top.scad, case_top.stl]
2025-02-16 Improve print settings chapter
2025-03-27 Fix link to wrong hotswap sockets
2025-04-14 [firmware] Various improvements
    Use PWM driver instead of bitbanging for rgb lighting
    Move oled task to sharkropad file and improve effect handling with automatic effect list generation and automatic scrolling for effect names that don't fit a single line
2025-05-13 Add switches to needed parts
